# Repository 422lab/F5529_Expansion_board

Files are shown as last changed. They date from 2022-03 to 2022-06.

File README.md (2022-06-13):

# MSP430F5529 LaunchPad扩展板
Master分支扩展板版本编号为V2.2，适用的案例工程为[MSP430F5529 LaunchPad 扩展板V2.1/V2.2案例工程](https://github.com/422lab/F5529_EXboard_Example)  
## 特性
* MSP430F5529 LaunchPad直插
* 多种显示屏支持
* LaunchPad全IO引出，标记编号以其复用功能
* 以上功能均可通过跳线帽和排线更改引脚
* 尽可能的硬件SPI支持
## 支持板载资源
* MSP430F5529 LaunchPad
* LCD12864
* 通用的4线I2C显示屏以及7/8线SPI显示屏
* ADS1118 / ADS1256(注意电源)
* DAC8571
* REF3330
* 4 * 4小键盘
## 注意事项
* 基于Kicad 5.1.12，向上Kicad6兼容，但是Kicad6不向下兼容，若后续有意使用Kicad6更新，最好创建一个新分支
* gerber文件请自行生成
* 可能会显示缺少符号库和封装库，已经放在仓库里了，自行重新导入一下  
## 实物图及使用说明
### 整体实物图(未插上模块和单片机)
焊接时注意哪些是排针哪些是排母，DIP插座可以由排母代替  
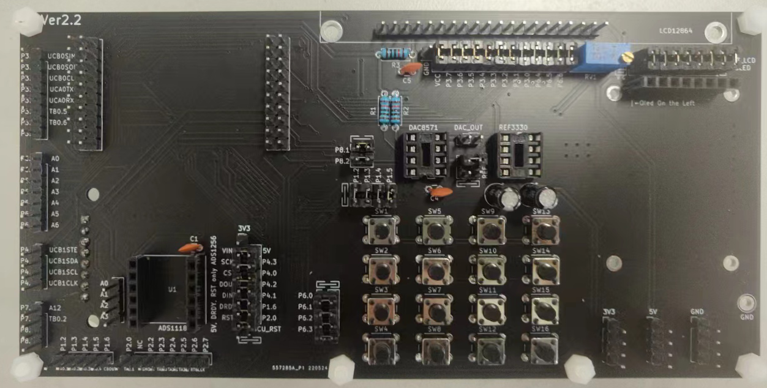
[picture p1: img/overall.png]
  
### 整体实物图(插上模块和单片机)
仅演示，实际上ADS1118和ADS1256不能同时使用，REF3330非必要模块
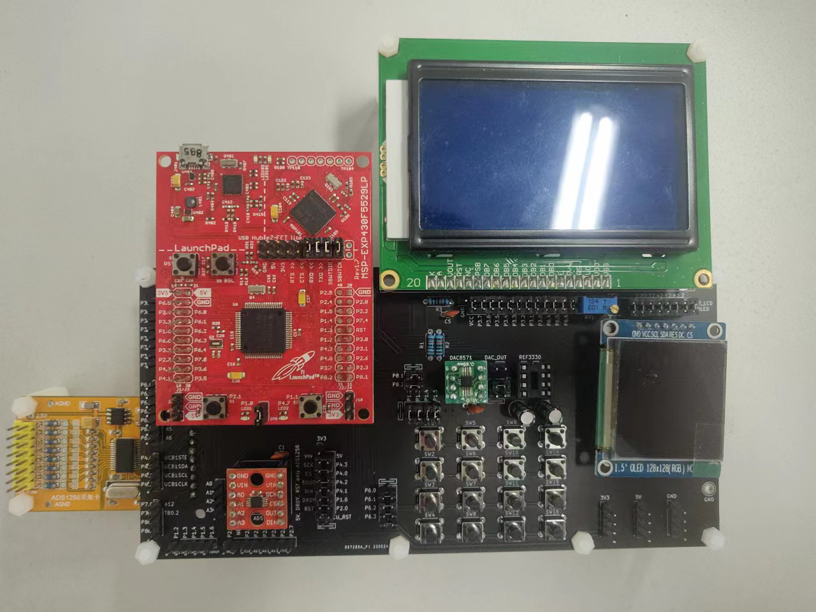
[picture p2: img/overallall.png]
  
### 实物背面
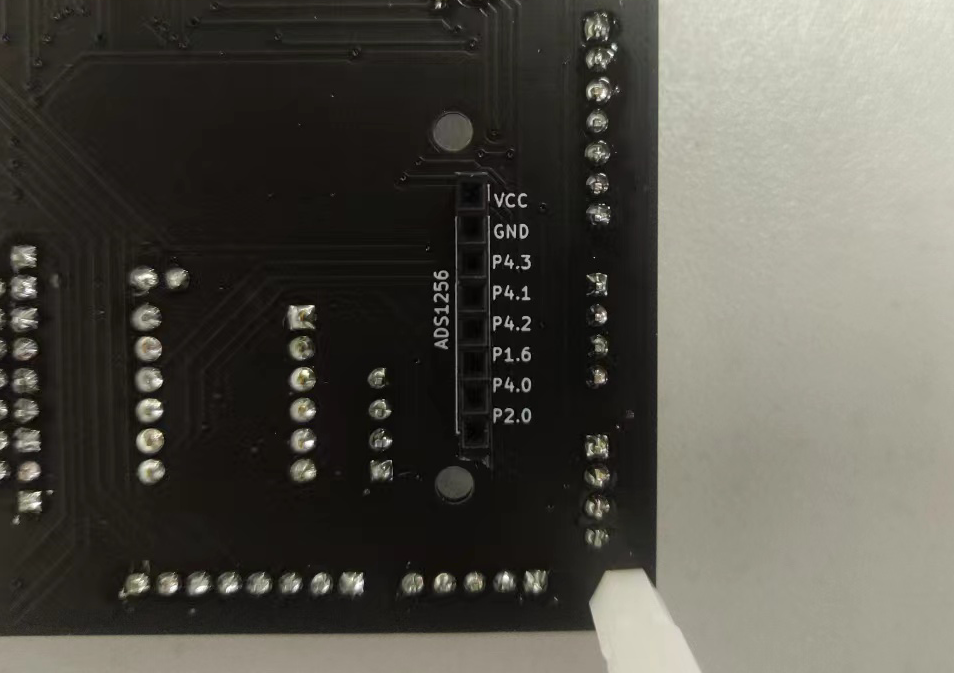
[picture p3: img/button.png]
实物背面
  
### OLED/LCD显示屏  
一般市面上的OLED/LCD显示屏都是7线/8线接口，且通常前两个引脚的顺序为GND VCC(3V3)，所以此OLED/LCD显示屏接口可以兼容这些显示屏
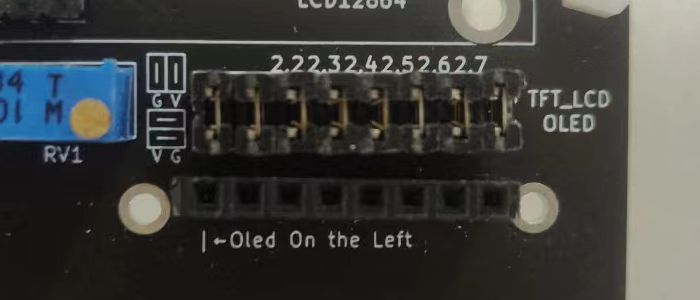
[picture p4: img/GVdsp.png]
  
当然也有一些脑回路新奇角度刁钻的店家推出了前两个引脚顺序为VCC GND的显示屏，所以进行了兼容，将前两个跳线帽横过来连接即可将前两个引脚顺序改为VCC GND
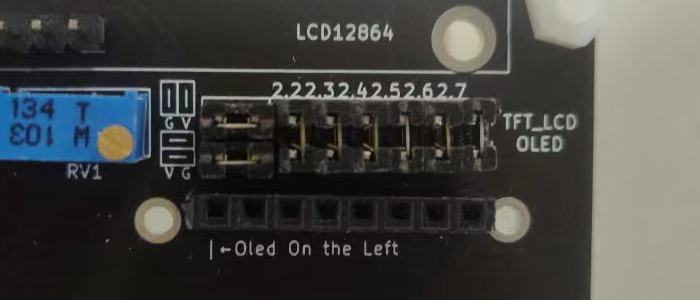
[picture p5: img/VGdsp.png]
  
这个显示屏接口兼容但不限于以下几个显示屏  
SSD1306 SPI (样例源码支持)  
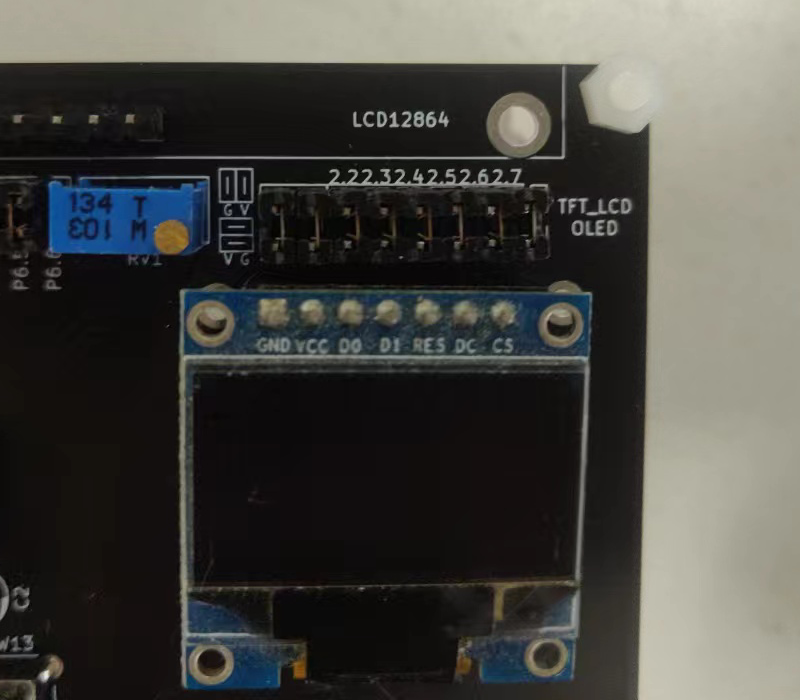
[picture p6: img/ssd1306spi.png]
SSD1306 SPI
  
SSD1306 I2C  
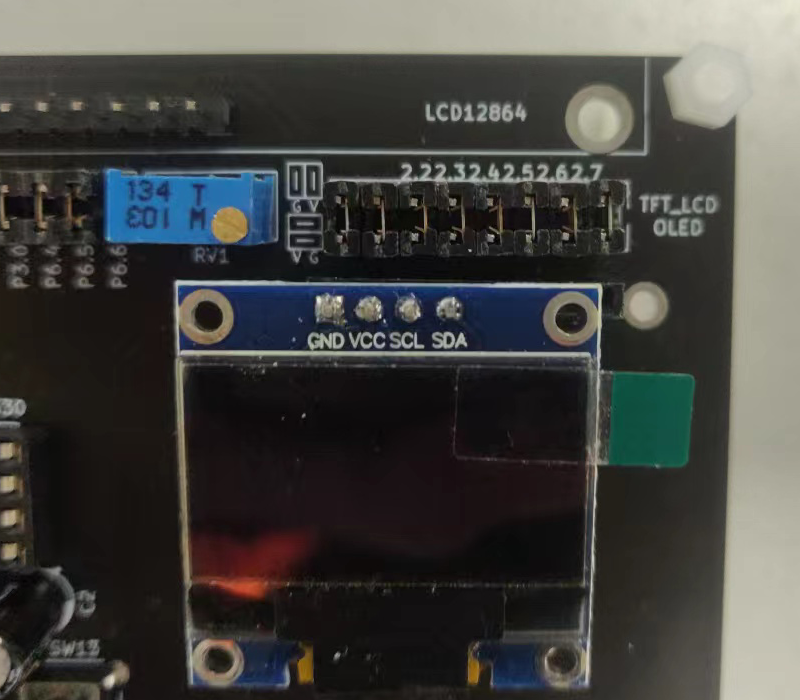
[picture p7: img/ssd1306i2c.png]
SSD1306 I2C
  
SSD1351 (样例源码支持)  
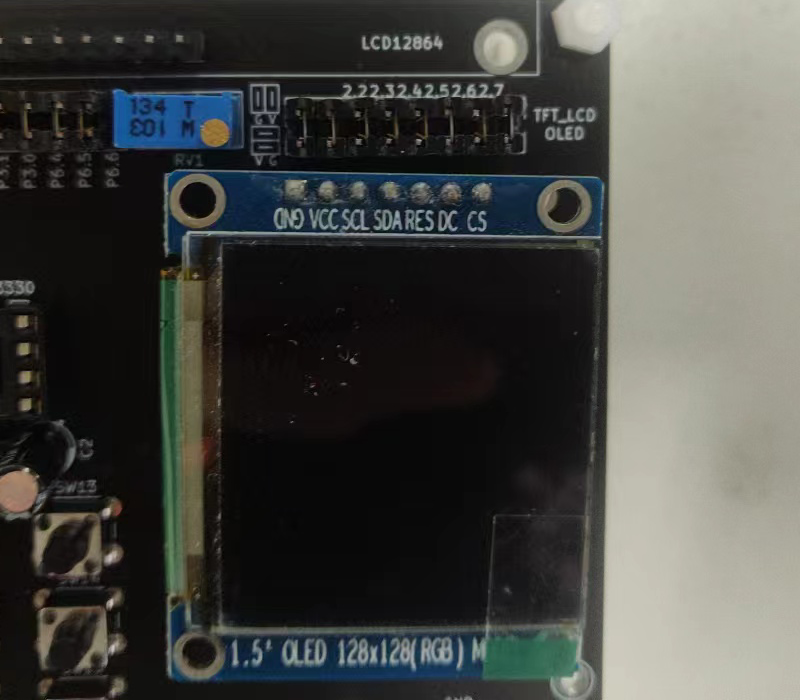
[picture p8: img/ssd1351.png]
SSD1351
  
GC9A01
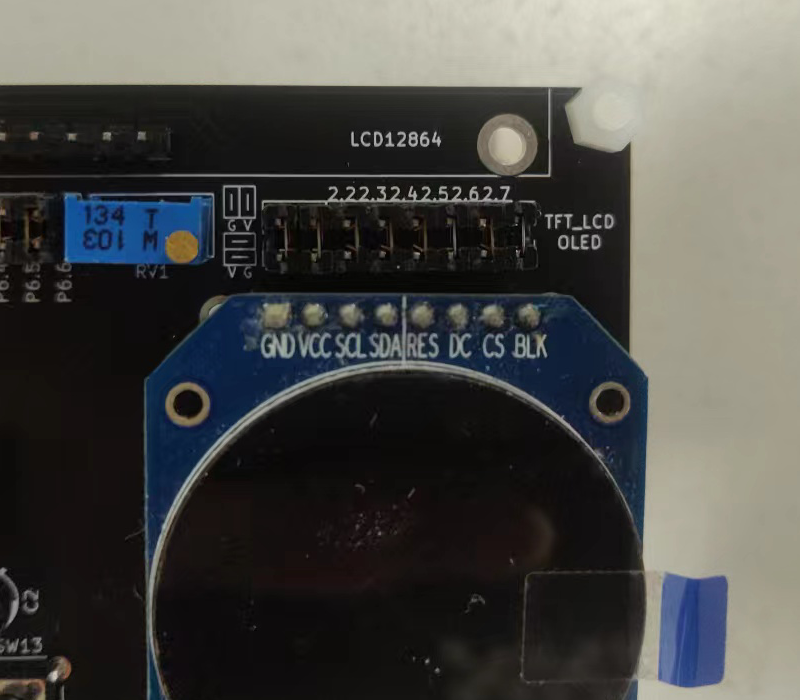
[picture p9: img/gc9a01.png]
GC9A01
  
### LCD12864
LCD12864支持两种接线模式，一种是4bit/8bit并行接口，另一种是SPI串行接口，根据PSB引脚的电平决定，PSB的电平可以由跳线帽更变，电位器用作改变LCD12864的对比度，不过需要在LCD12864自身短接一个焊点才能生效，所以非必要元件
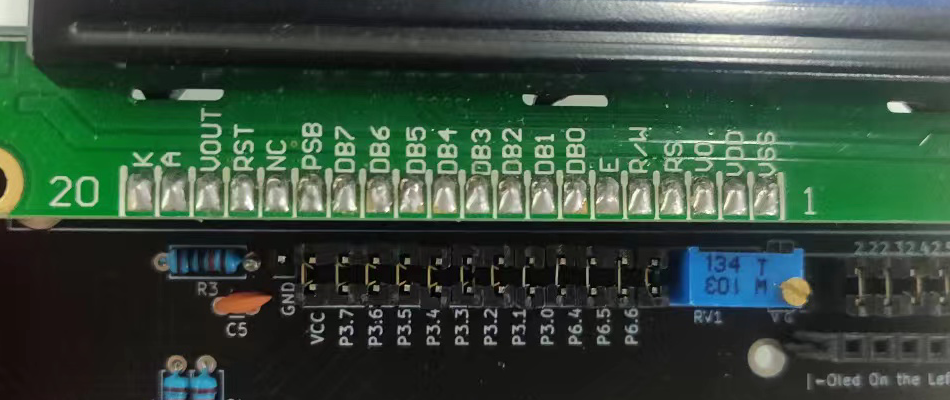
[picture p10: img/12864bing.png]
LCD12864 8bit LCD12864

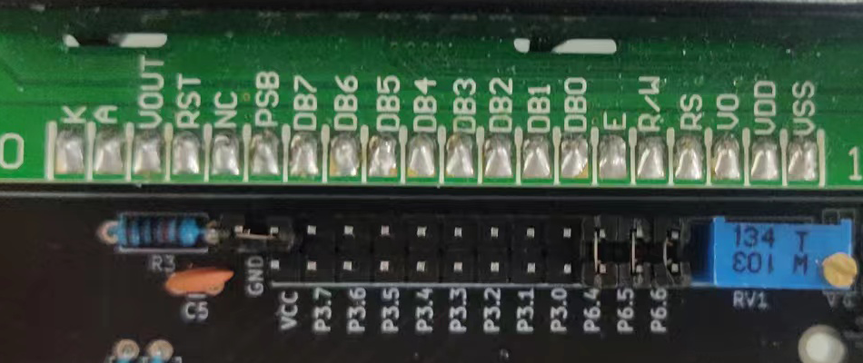
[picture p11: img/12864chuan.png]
LCD12864 SPI LCD12864

### 矩阵键盘  
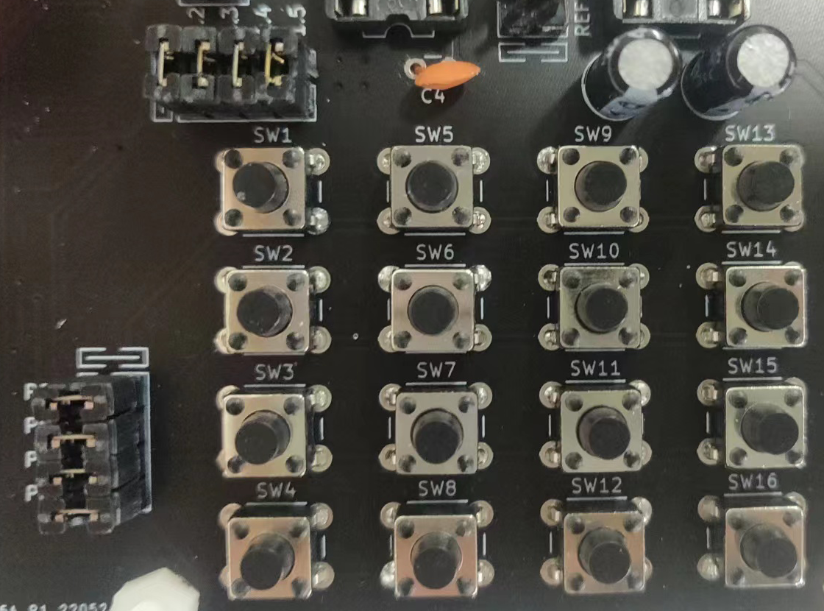
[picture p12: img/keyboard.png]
KeyBoard

### DAC8571 
DAC8571在扩展底板上支持两个电压参考源，一个是3.3V，另一个是来自REF3330的3.0V，可以根据跳线帽更改
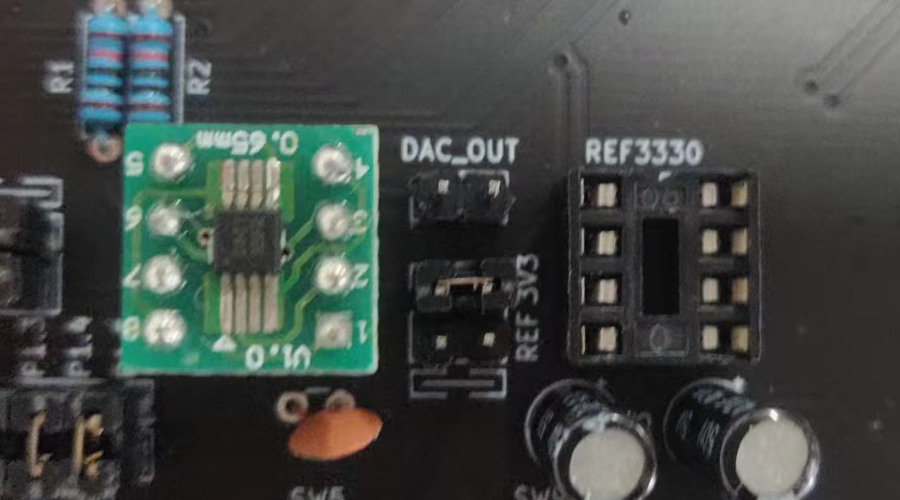
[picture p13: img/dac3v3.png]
DAC8571 3V3

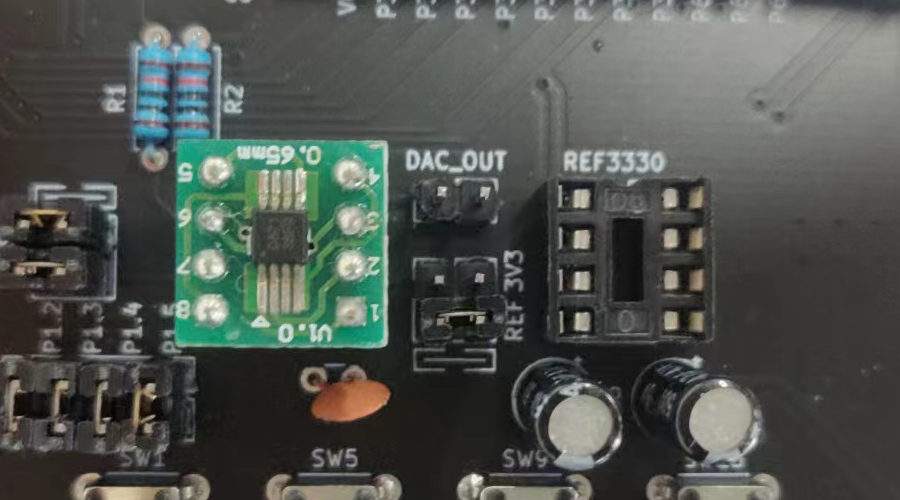
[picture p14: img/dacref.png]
DAC8571 REF
  
### ADS1256/ADS1118
扩展底板可以的外挂ADC模块有16位精度的ADS1118和24位精度的ADS1256，两者不可同时使用，其中请注意，ADS1256使用的5V供电，ADS1118使用3V3供电(芯片手册上说支持5V，但是我5V接一片烧一片就很迷)，可以通过跳线帽的进行更改  
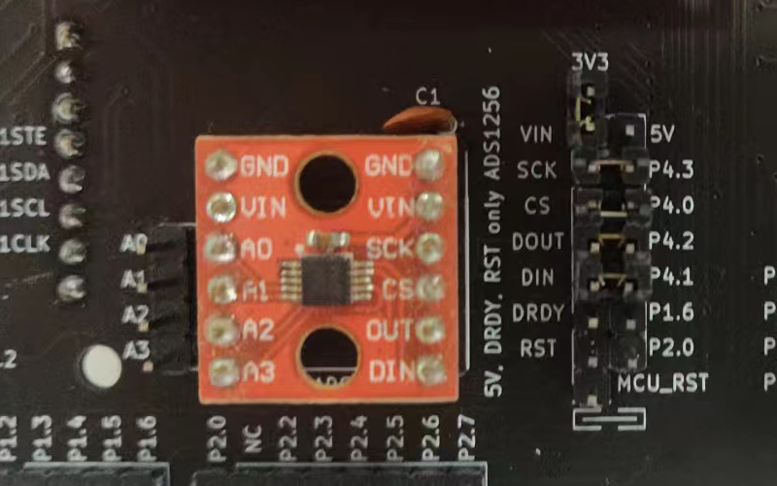
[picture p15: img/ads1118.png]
ADS1118

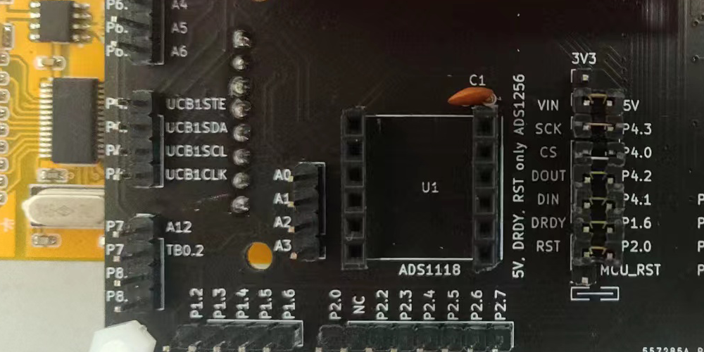
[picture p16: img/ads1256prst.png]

另外相比于ADS1118，ADS1256多了DRDY和RST两个引脚，DRDY用于判忙，RST用于硬复位，所以可以将ADS1256的RST与单片机的RST通过改变跳线帽连接在一起共用一个硬件复位，关键时刻还是能省一个GPIO的
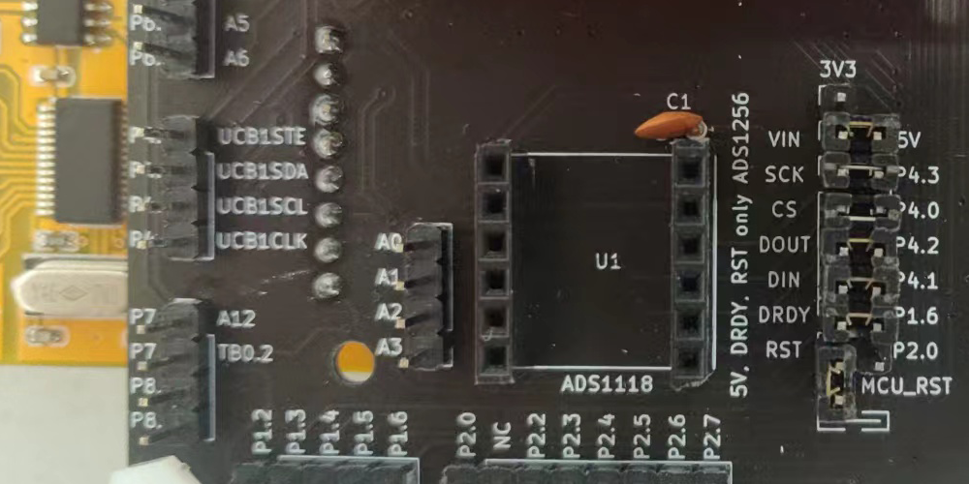
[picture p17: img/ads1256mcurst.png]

至此，扩展底板实物大致介绍完毕

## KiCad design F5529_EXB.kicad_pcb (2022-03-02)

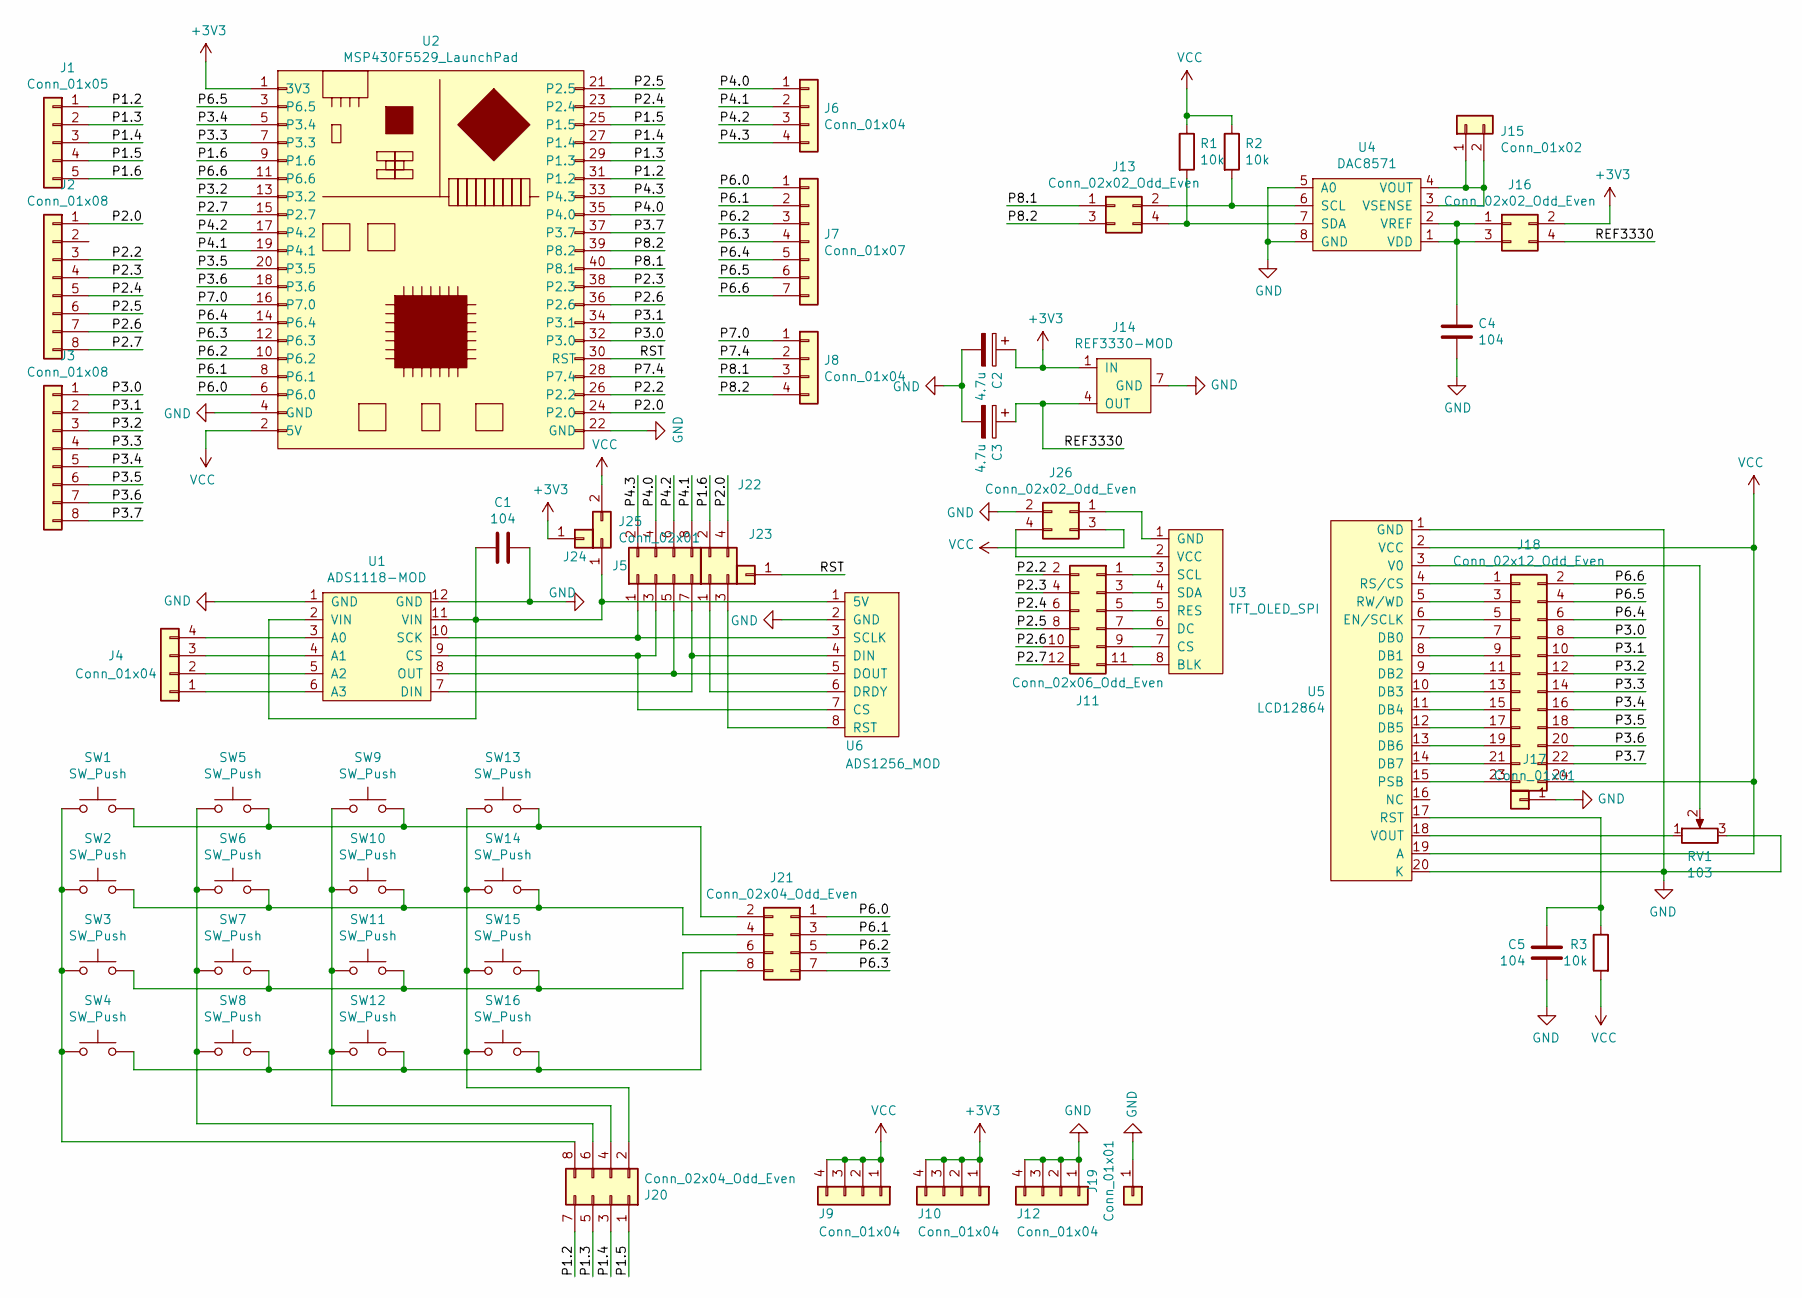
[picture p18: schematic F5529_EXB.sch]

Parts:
C1, C4, C5: 104; C_Disc_D3.0mm_W1.6mm_P2.50mm
C2, C3: 4.7u; CP_Radial_D5.0mm_P2.50mm
J1: Conn_01x05; PinHeader_1x05_P2.54mm_Vertical
J2, J3: Conn_01x08; PinHeader_1x08_P2.54mm_Vertical
J4, J6, J8, J9, J10, J12: Conn_01x04; PinHeader_1x04_P2.54mm_Vertical
J5, J20, J21: Conn_02x04_Odd_Even; PinHeader_2x04_P2.54mm_Vertical
J7: Conn_01x07; PinHeader_1x07_P2.54mm_Vertical
J11: Conn_02x06_Odd_Even; PinHeader_2x06_P2.54mm_Vertical
J13, J16, J22, J26: Conn_02x02_Odd_Even; PinHeader_2x02_P2.54mm_Vertical
J14: REF3330-MOD; DIP-8_W7.62mm
J15: Conn_01x02; PinHeader_1x02_P2.54mm_Vertical
J17, J23, J24: Conn_01x01; PinHeader_1x01_P2.54mm_Vertical
J18: Conn_02x12_Odd_Even; PinHeader_2x12_P2.54mm_Vertical
J19: Conn_01x01; TestPoint_Loop_D2.50mm_Drill1.85mm
J25: Conn_02x01; PinHeader_2x01_P2.54mm_Vertical
R1, R2, R3: 10k; R_Axial_DIN0207_L6.3mm_D2.5mm_P7.62mm_Horizontal
RV1: 103; Potentiometer_Bourns_3296W_Vertical
SW1, SW2, SW3, SW4, SW5, SW6, SW7, SW8, SW9, SW10, SW11, SW12, SW13, SW14, SW15, SW16: SW_Push; SW_PUSH_6mm
U1: ADS1118-MOD; ADS1118_MOD
U2: MSP430F5529_LaunchPad
U3: TFT_OLED_SPI; ZJY_1_54_SPI_ST7789
U4: DAC8571; DIP-8_W7.62mm
U5: LCD12864
U6: ADS1256_MOD; PinSocket_1x08_P2.54mm_Vertical

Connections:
+3V3: C2.1, J10.1, J10.2, J10.3, J10.4, J14.1 (IN), J16.2, J24.1, U2.1 (3V3)
/P1.2: J1.1, J20.7, U2.31 (P1.2)
/P1.3: J1.2, J20.5, U2.29 (P1.3)
/P1.4: J1.3, J20.3, U2.27 (P1.4)
/P1.5: J1.4, J20.1, U2.25 (P1.5)
/P1.6: J1.5, J22.2, U2.9 (P1.6)
/P2.0: J2.1, J22.4, U2.24 (P2.0)
/P2.2: J2.3, J11.2, U2.26 (P2.2)
/P2.3: J2.4, J11.4, U2.38 (P2.3)
/P2.4: J2.5, J11.6, U2.23 (P2.4)
/P2.5: J2.6, J11.8, U2.21 (P2.5)
/P2.6: J2.7, J11.10, U2.36 (P2.6)
/P2.7: J2.8, J11.12, U2.15 (P2.7)
/P3.0: J3.1, J18.8, U2.32 (P3.0)
/P3.1: J3.2, J18.10, U2.34 (P3.1)
/P3.2: J3.3, J18.12, U2.13 (P3.2)
/P3.3: J3.4, J18.14, U2.7 (P3.3)
/P3.4: J3.5, J18.16, U2.5 (P3.4)
/P3.5: J3.6, J18.18, U2.20 (P3.5)
/P3.6: J3.7, J18.20, U2.18 (P3.6)
/P3.7: J3.8, J18.22, U2.37 (P3.7)
/P4.0: J5.4, J6.1, U2.35 (P4.0)
/P4.1: J5.8, J6.2, U2.19 (P4.1)
/P4.2: J5.6, J6.3, U2.17 (P4.2)
/P4.3: J5.2, J6.4, U2.33 (P4.3)
/P6.0: J7.1, J21.1, U2.6 (P6.0)
/P6.1: J7.2, J21.3, U2.8 (P6.1)
/P6.2: J7.3, J21.5, U2.10 (P6.2)
/P6.3: J7.4, J21.7, U2.12 (P6.3)
/P6.4: J7.5, J18.6, U2.14 (P6.4)
/P6.5: J7.6, J18.4, U2.3 (P6.5)
/P6.6: J7.7, J18.2, U2.11 (P6.6)
/P7.0: J8.1, U2.16 (P7.0)
/P7.4: J8.2, U2.28 (P7.4)
/P8.1: J8.3, J13.1, U2.40 (P8.1)
/P8.2: J8.4, J13.3, U2.39 (P8.2)
/REF3330: C3.1, J14.4 (OUT), J16.4
/RST: J23.1, U2.30 (RST)
GND: C1.1, C2.2, C3.2, C4.2, C5.2, J12.1, J12.2, J12.3, J12.4, J14.7 (GND), J17.1, J19.1, J26.2, RV1.3, U1.1 (GND), U1.12 (GND), U2.4 (GND), U2.22 (GND), U4.5 (A0), U4.8 (GND), U5.1 (GND), U5.20 (K), U6.2 (GND)
unnamed: C1.2, J25.1, U1.2 (VIN), U1.11 (VIN), U6.1 (5V)
unnamed: C4.1, J16.1, J16.3, U4.1 (VDD), U4.2 (VREF)
unnamed: C5.1, R3.1, U5.17 (RST)
unnamed: J4.1, U1.6 (A3)
unnamed: J4.2, U1.5 (A2)
unnamed: J4.3, U1.4 (A1)
unnamed: J4.4, U1.3 (A0)
unnamed: J5.1, U1.10 (SCK), U6.3 (SCLK)
unnamed: J5.3, U1.9 (CS), U6.7 (CS)
unnamed: J5.5, U1.8 (OUT), U6.5 (DOUT)
unnamed: J5.7, U1.7 (DIN), U6.4 (DIN)
unnamed: J11.1, U3.3 (SCL)
unnamed: J11.3, U3.4 (SDA)
unnamed: J11.5, U3.5 (RES)
unnamed: J11.7, U3.6 (DC)
unnamed: J11.9, U3.7 (CS)
unnamed: J11.11, U3.8 (BLK)
unnamed: J13.2, R2.2, U4.6 (SCL)
unnamed: J13.4, R1.2, U4.7 (SDA)
unnamed: J15.1, J15.2, U4.3 (VSENSE), U4.4 (VOUT)
unnamed: J18.1, U5.4 (RS/CS)
unnamed: J18.3, U5.5 (RW/WD)
unnamed: J18.5, U5.6 (EN/SCLK)
unnamed: J18.7, U5.7 (DB0)
unnamed: J18.9, U5.8 (DB1)
unnamed: J18.11, U5.9 (DB2)
unnamed: J18.13, U5.10 (DB3)
unnamed: J18.15, U5.11 (DB4)
unnamed: J18.17, U5.12 (DB5)
unnamed: J18.19, U5.13 (DB6)
unnamed: J18.21, U5.14 (DB7)
unnamed: J18.23, U5.15 (PSB)
unnamed: J20.2, SW13.1, SW14.1, SW15.1, SW16.1
unnamed: J20.4, SW9.1, SW10.1, SW11.1, SW12.1
unnamed: J20.6, SW5.1, SW6.1, SW7.1, SW8.1
unnamed: J20.8, SW1.1, SW2.1, SW3.1, SW4.1
unnamed: J21.2, SW1.2, SW5.2, SW9.2, SW13.2
unnamed: J21.4, SW2.2, SW6.2, SW10.2, SW14.2
unnamed: J21.6, SW3.2, SW7.2, SW11.2, SW15.2
unnamed: J21.8, SW4.2, SW8.2, SW12.2, SW16.2
unnamed: J22.1, U6.6 (DRDY)
unnamed: J22.3, U6.8 (RST)
unnamed: J26.1, U3.1 (GND)
unnamed: J26.4, U3.2 (VCC)
unnamed: RV1.1, U5.18 (VOUT)
unnamed: RV1.2, U5.3 (V0)
VCC: J9.1, J9.2, J9.3, J9.4, J18.24, J25.2, J26.3, R1.1, R2.1, R3.2, U2.2 (5V), U5.2 (VCC), U5.19 (A)

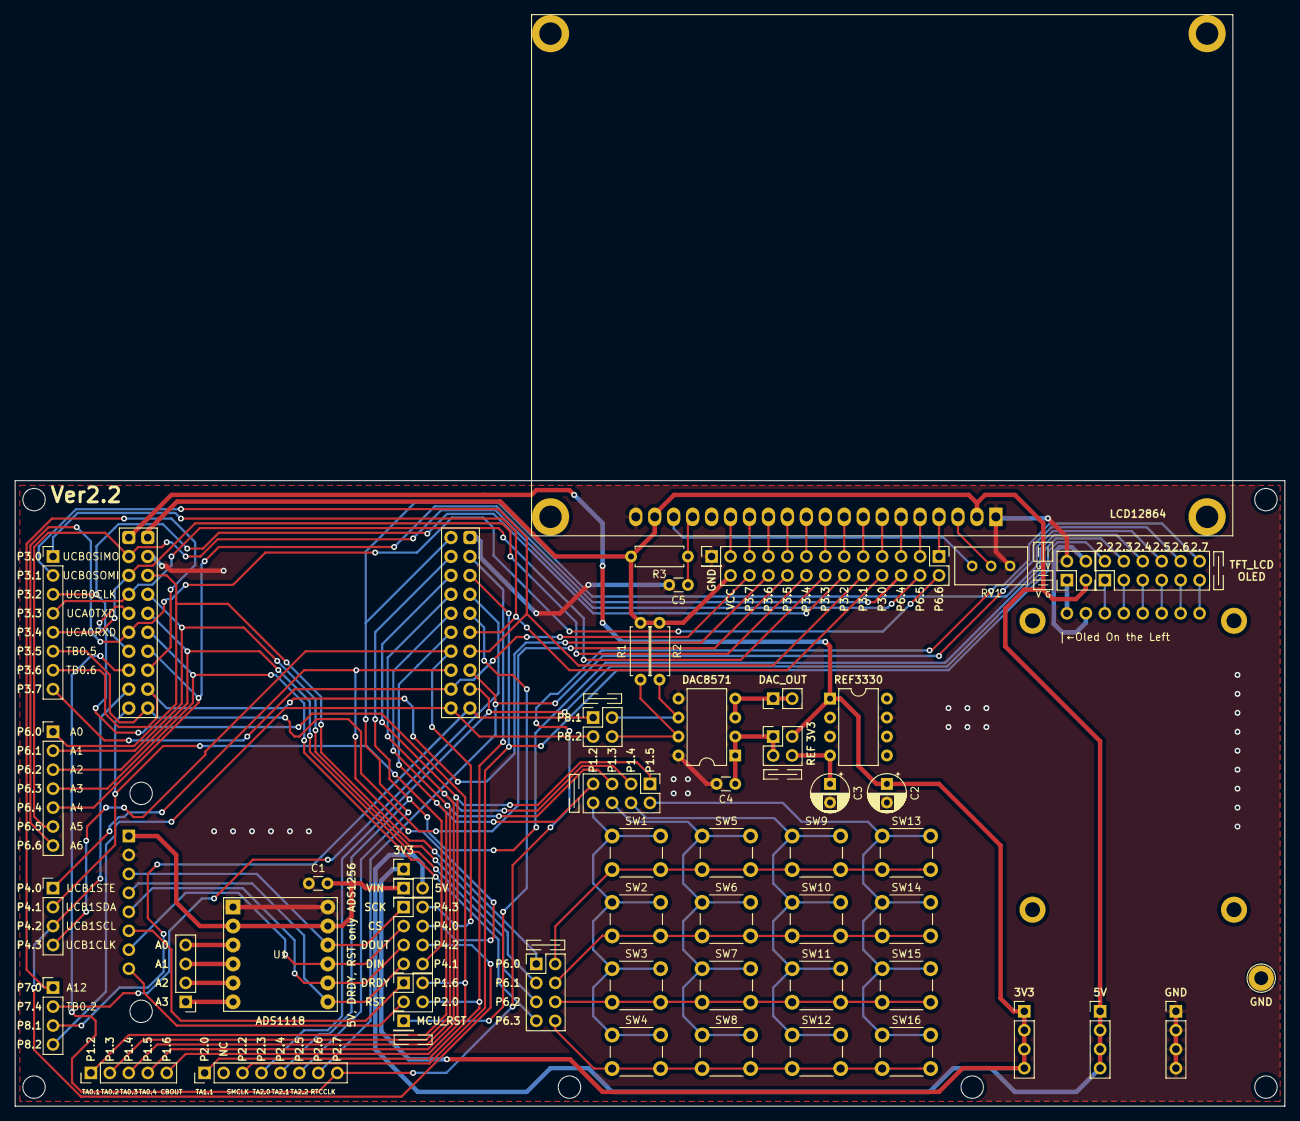
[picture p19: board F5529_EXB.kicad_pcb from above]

Board: 2 copper layers, 170.2 x 83.8 mm, 57 parts (1 on the bottom side), 86 nets.

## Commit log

2022-03-02 仓库初始化
    [F5529_EXB.kicad_pcb, F5529_EXB.sch]
2022-05-16 描述修改，增加案例工程链接地址
2022-06-13 更新实物图片，更新README介绍
